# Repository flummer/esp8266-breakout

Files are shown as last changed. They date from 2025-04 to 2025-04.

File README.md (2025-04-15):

# ESP8266 Breakout Board

This is a simple breakout board for the ESP8266-12E/F modules, designed to be easy to use with the [WLED Project](https://kno.wled.ge/) and also possible to solder without too much trouble using a regular soldering iron.

It's relatively bare bone and only have the minimum required, though 2 buttons are included to make it easier to reset and flash the controller. The buttons can be omitted and simply shorted when programming, as they are not needed for running WLED.

## BOM

The [Interactive HTML BOM](https://html-preview.github.io/?url=https://github.com/flummer/esp8266-breakout/blob/main/bom/ibom.html) is included for assistance with assembly.

## Designed in KiCad v9

To open the project, you will need to install v9 or a recent nightly build, KiCad v8 or earlier won't open this design directly.

[Electronics schematics as a PDF file](https://github.com/flummer/esp8266-breakout/blob/main/ESP8266-Breakout-Schematic.pdf) is also included for reference.

You can also have a look at the design using [KiCanvas](https://kicanvas.org/?github=https%3A%2F%2Fgithub.com%2Fflummer%2Fesp8266-breakout).

## License

The hardware design of the `main` branch of this repository is released under the following license:

* the "Creative Commons Attribution-ShareAlike 4.0 International License"
  (CC BY-SA 4.0) full text of this license is included in the LICENSE file
  and a copy can also be found at
  [http://creativecommons.org/licenses/by-sa/4.0/](http://creativecommons.org/licenses/by-sa/4.0/)

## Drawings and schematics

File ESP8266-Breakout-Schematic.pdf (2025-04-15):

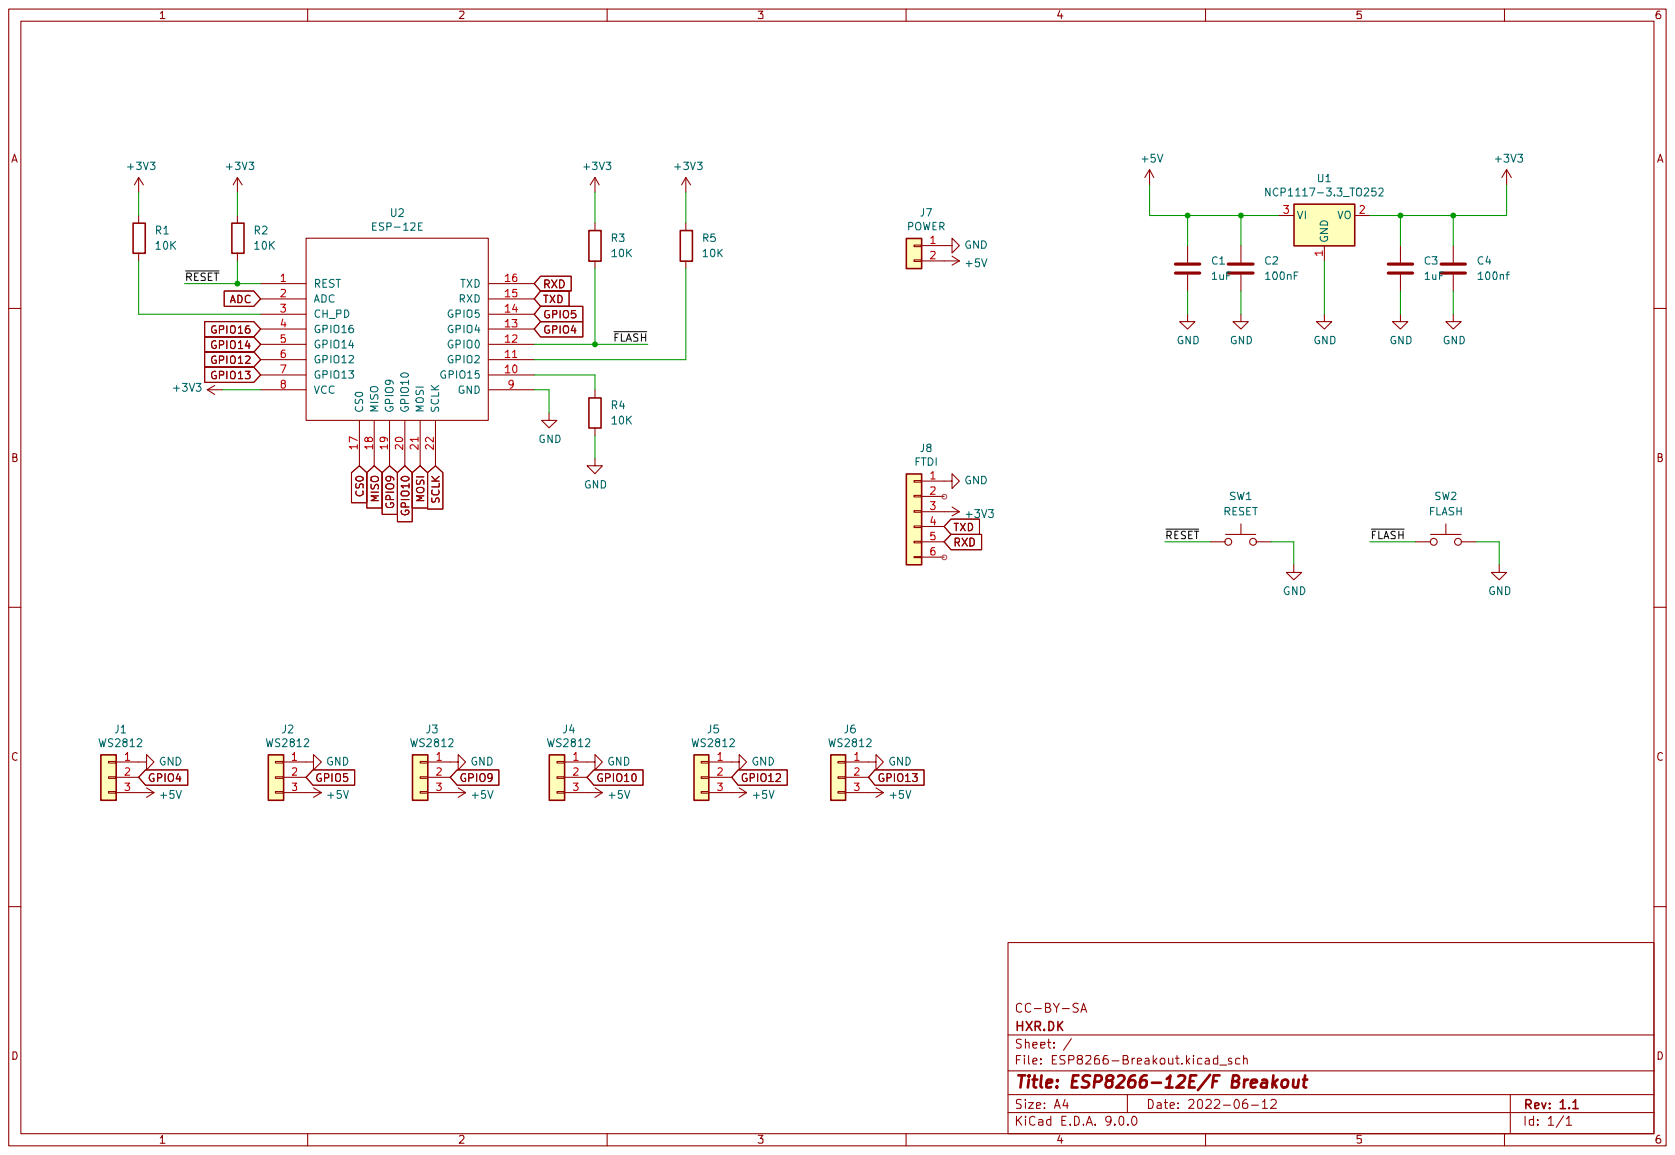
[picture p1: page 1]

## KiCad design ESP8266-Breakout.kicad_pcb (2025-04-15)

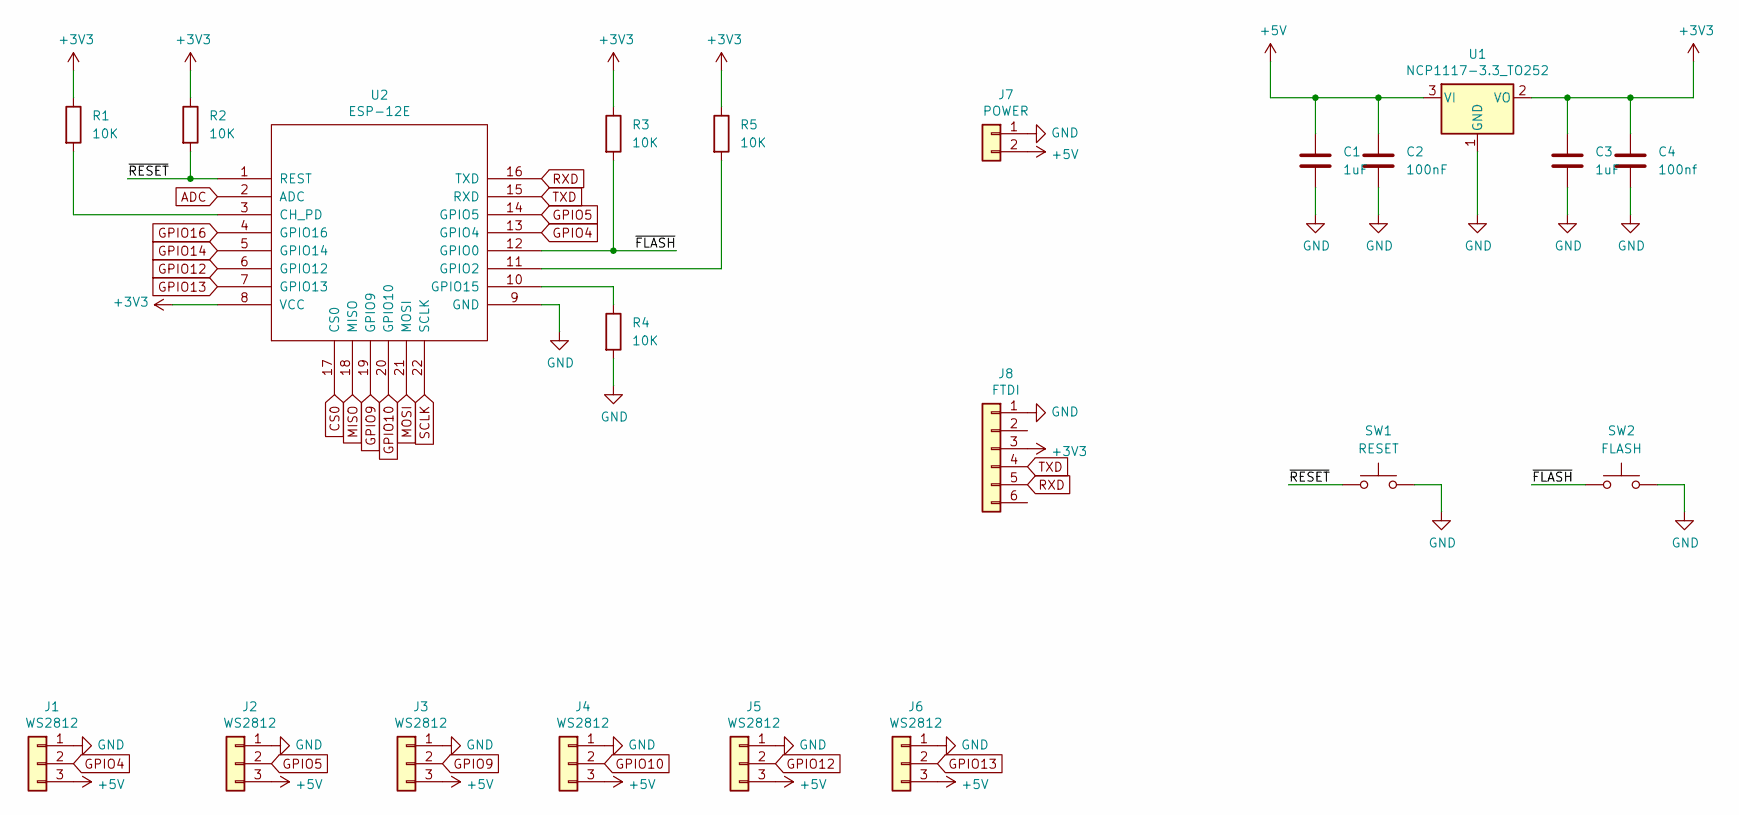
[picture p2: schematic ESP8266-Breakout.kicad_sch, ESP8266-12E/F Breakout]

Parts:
C1, C3: 1uF; C_0805_2012Metric_Pad1.18x1.45mm_HandSolder
C2: 100nF; C_0805_2012Metric_Pad1.18x1.45mm_HandSolder
C4: 100nf; C_0805_2012Metric_Pad1.18x1.45mm_HandSolder
J1, J2, J3, J4, J5, J6: WS2812; PinHeader_1x03_P2.54mm_Vertical
J7: POWER; PinHeader_1x02_P2.54mm_Vertical
J8: FTDI; PinHeader_1x06_P2.54mm_Vertical
R1, R2, R3, R4, R5: 10K; R_0805_2012Metric_Pad1.20x1.40mm_HandSolder
SW1: RESET; SW_SPST_TL3342
SW2: FLASH; SW_SPST_TL3342
U1: NCP1117-3.3_TO252; TO-252-2
U2: ESP-12E; ESP-12E_SMD

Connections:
+3V3: C3.1, C4.1, J8.3, R1.1, R2.1, R3.1, R5.1, U1.2 (VO), U2.8 (VCC)
+5V: C1.1, C2.1, J1.3, J2.3, J3.3, J4.3, J5.3, J6.3, J7.2, U1.3 (VI)
/~FLASH: R3.2, SW2.1, U2.12 (GPIO0)
/~RESET: R2.2, SW1.1, U2.1 (REST)
ADC: U2.2 (ADC)
CS0: U2.17 (CS0)
GND: C1.2, C2.2, C3.2, C4.2, J1.1, J2.1, J3.1, J4.1, J5.1, J6.1, J7.1, J8.1, R4.2, SW1.2, SW2.2, U1.1 (GND), U2.9 (GND)
GPIO4: J1.2, U2.13 (GPIO4)
GPIO5: J2.2, U2.14 (GPIO5)
GPIO9: J3.2, U2.19 (GPIO9)
GPIO10: J4.2, U2.20 (GPIO10)
GPIO12: J5.2, U2.6 (GPIO12)
GPIO13: J6.2, U2.7 (GPIO13)
GPIO14: U2.5 (GPIO14)
GPIO16: U2.4 (GPIO16)
MISO: U2.18 (MISO)
MOSI: U2.21 (MOSI)
unnamed: R1.2, U2.3 (CH_PD)
unnamed: R5.2, U2.11 (GPIO2)
unnamed: R4.1, U2.10 (GPIO15)
RXD: J8.5, U2.16 (TXD)
SCLK: U2.22 (SCLK)
TXD: J8.4, U2.15 (RXD)

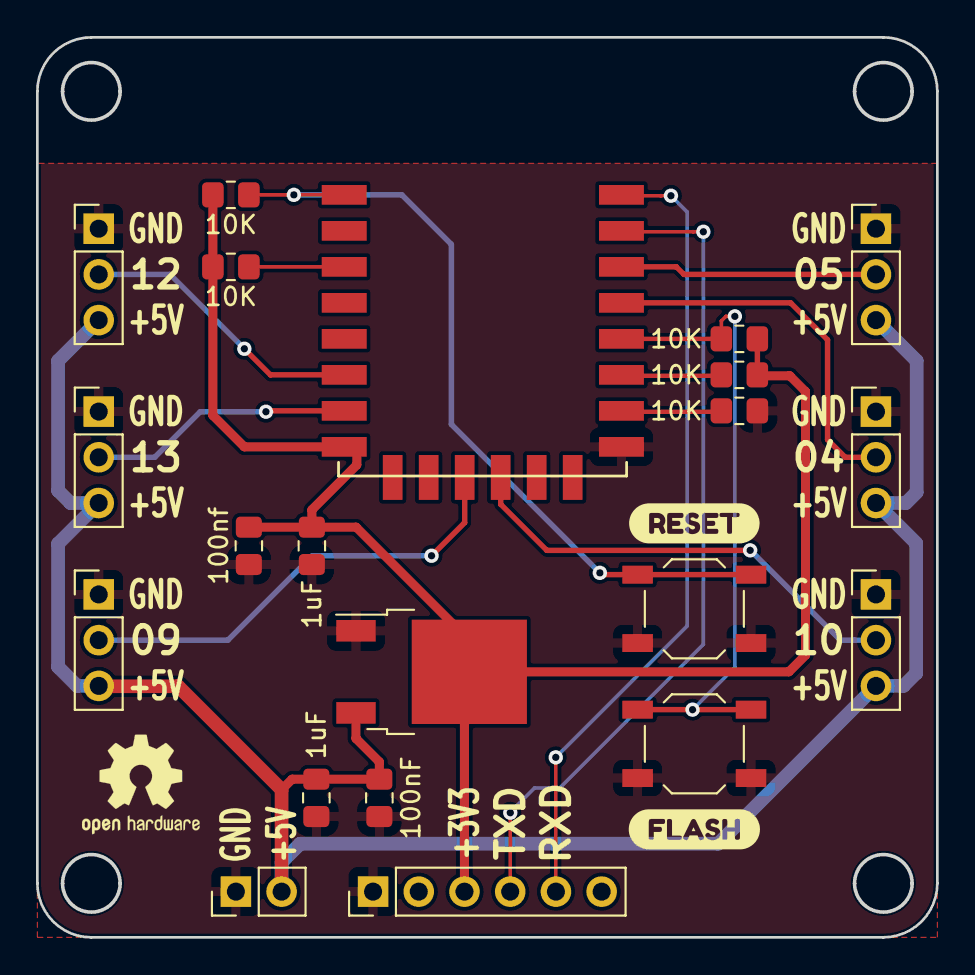
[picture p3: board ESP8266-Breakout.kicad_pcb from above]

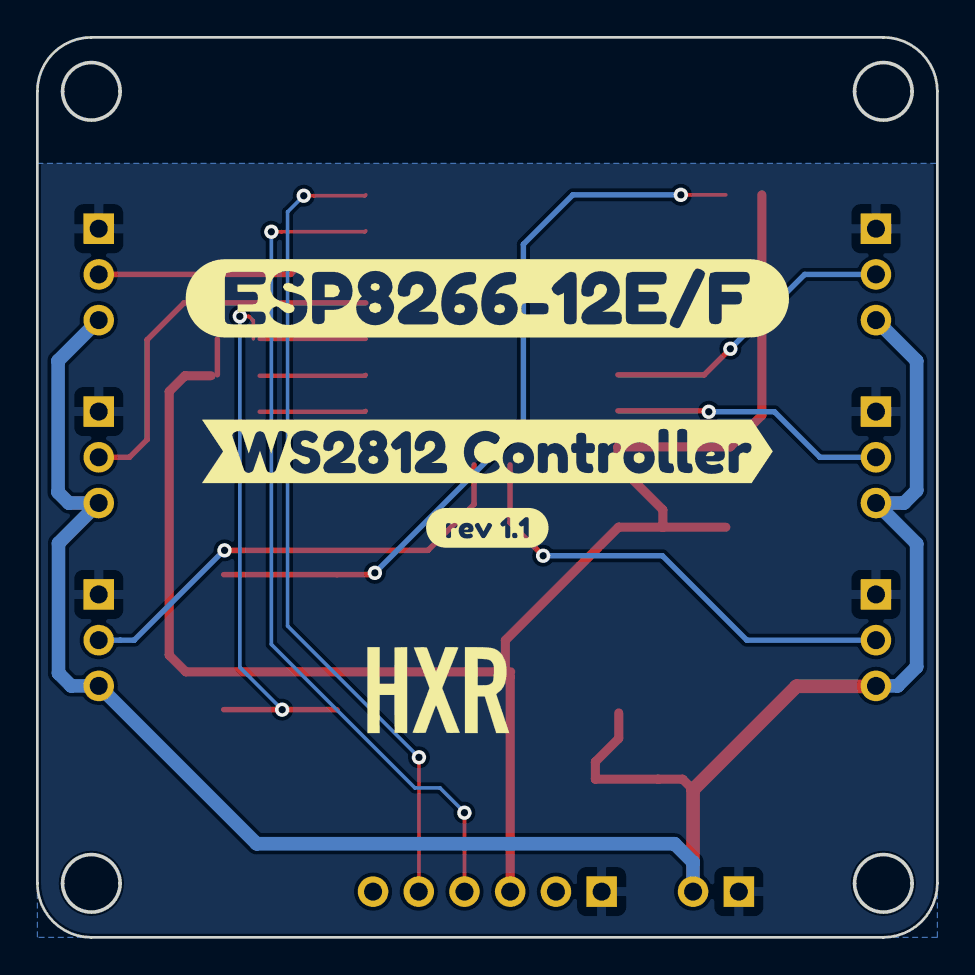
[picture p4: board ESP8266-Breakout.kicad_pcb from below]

Board: 2 copper layers, 50.0 x 50.0 mm, 26 parts (3 on the bottom side), 16 nets.

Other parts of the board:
kibuzzard-62A653A7: G***; kibuzzard-62A653A7
kibuzzard-62A6539A: G***; kibuzzard-62A6539A
kibuzzard-62A6554C: G***; kibuzzard-62A6554C
kibuzzard-62A6557D: G***; kibuzzard-62A6557D
kibuzzard-62A65508: G***; kibuzzard-62A65508
